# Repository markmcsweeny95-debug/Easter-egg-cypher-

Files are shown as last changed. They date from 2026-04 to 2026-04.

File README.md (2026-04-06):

# Easter-egg-cypher-
I am hosting an easter egg hunt for some family friends this year and i want to make it super exciting so i will use an arduino and a joystick where they will find clues (icons) and when they put them in it will give them a word and that will be their next clue.










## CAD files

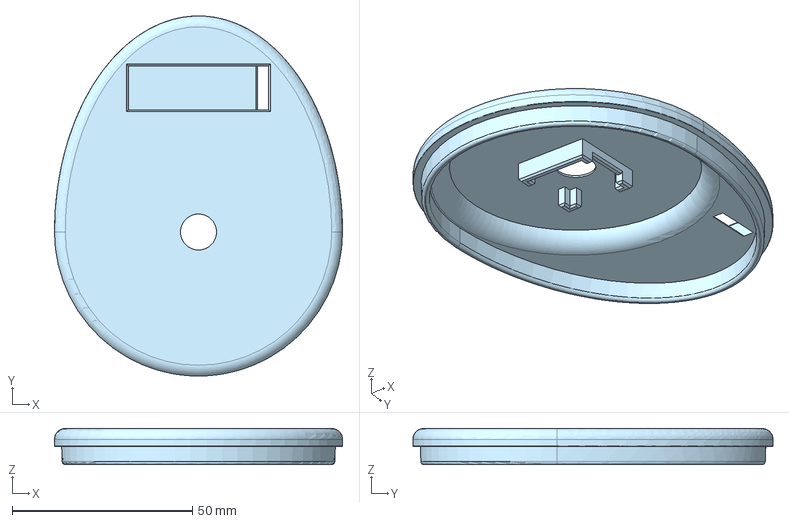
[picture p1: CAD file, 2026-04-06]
Easter egg cypher LID.step
80.0 x 100.0 x 10.0 mm

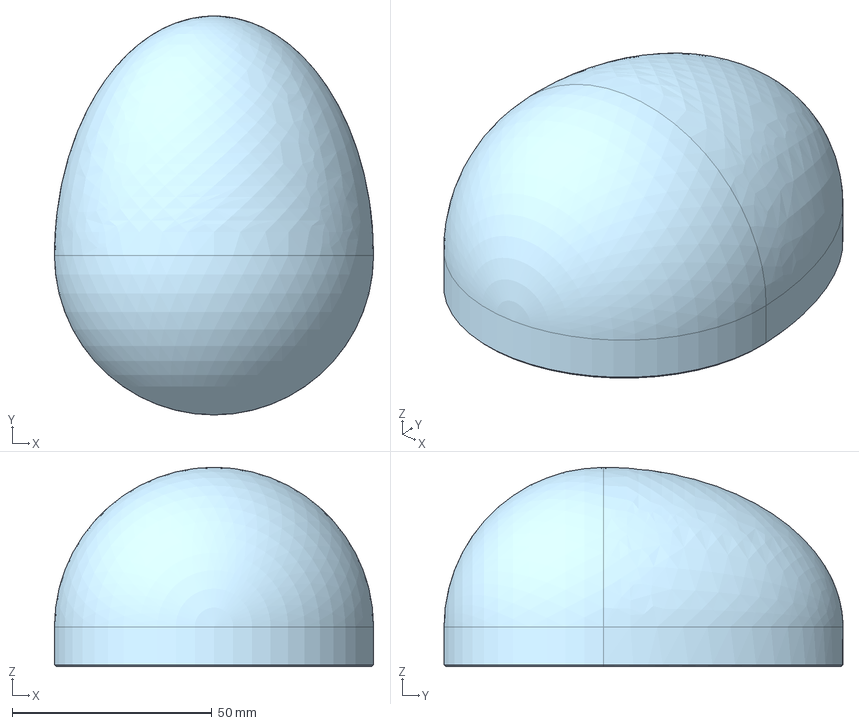
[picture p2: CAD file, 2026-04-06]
Easter egg cypher body.step
80.0 x 100.0 x 50.0 mm

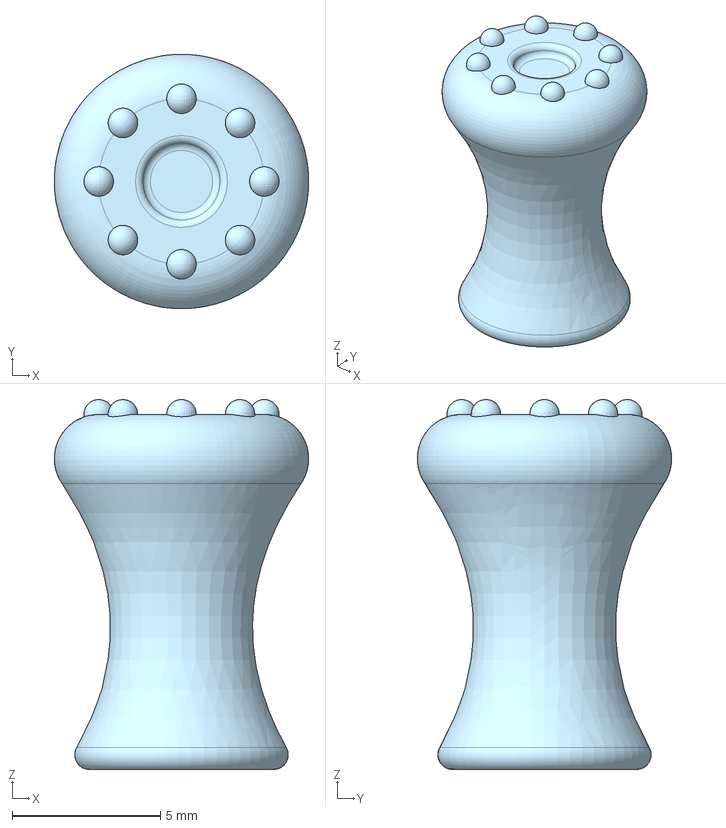
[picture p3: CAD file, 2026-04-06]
Joystick model.step
8.59 x 8.59 x 12.5 mm

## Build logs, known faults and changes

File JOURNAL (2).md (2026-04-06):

<!--
  This journal is auto generated by Stasis.
-->

# 4/6/2026 1 PM - Wiring parts

_Time spent: 0.4h_

Wiring the joystick module, OLED display, ESP32 S3 and Buzzer together.

-     Joystick wiring 
- -Ground to ESP32 ground
- -+5V to ESP32 3.3V 
- -VRx to GPIO 1 
- -VRy to GPIO 2 
- -SW to GPIO 4 
-      OLED display wiring
- -SCK to GPIO 9
- -SDA to GPIO 8
- -VCC to 3.3v 
- -Ground to ESP32 ground
- 
-       AI DECLARATION (READ!)
- Used some very bad ai code to test that all the wiring was correct by testing the buzzer, OLED and joystick. I did this so i could quickly test the wiring before i move onto prooperly coding it
- 
-     Wiring images 
- 










# 4/6/2026 10 AM - Created final lid design and final body design

_Time spent: 0.9166666666666666h_

Finalised my 3d models...

- I now have completely finished 3d models of mmy design which i have also 3d printed which means that the next stage is wiring the parts together, posssibly soldering and then also writing the code for the project as well as painting the plastic egg to look more easter-y 
-     The finished 3d models (images)
- 










-     The Final lid model
-     Key features
- -Thinned out circular section on back to save space and filament 
- -Friction joystick mount 
- -Friction mounted OLED screen with pin holes through back to allow easy wiring 
- -Drafted lip which allows it to connect to main body tightly 
- -Circular hole in front for joystick arm to poke through 
- The thinned out section of the lid is really important because it allows the joystick body to be pushed right up to it meaning that there is plenty of clearence for the joystick arm on the other side. The thinned out section is 0.5mm thick which means there it needs the support from the surrounding thicker areas otherwise it would flex. The circular thinner section also looks really cool when you shine a torch from the other side because th elight goes through it, i may add an led strip in possibly as a feature to really enhance this feature. 
- The friction joystick mount was tricky to design because it involved taking very precise measuremts of the joystick module so that it holds it tightly so it doesn't fall out but i also had to be careful not to make the walls of it too high because then it would intefere with some of the moving parts of the joystick body which could damage the component or cause some really weird results. I had to use a friction mount because the plastic wall was no longer thick enough to support using a screw to hold in the joystick. It has some small chamfers at the top which allow the joystick to enter smoothly. 
- The friction mounted OLED screen design has not changed at all since the last design 
- The drafted lip has not changed since the last design 
- The circular hole in the front of the lid was designed to allow the joystick arm and the joystick attatchment to easily fit through it while also not being in the way of allowing the joystick arm to freely move. I designed it to be 10mm but the joystick hole is only 8mm, this means there is a clearance near the moving parts and also exposes some of the shiny metal which gives it a quite luxurious look.
-      The final model body
-      Key features 
- -Thick edge lip to attatch onto lid 
- -Flat section for 10mm to add extra space 
- -Smooth surface design 
- Most of the body is just 1mm thick which allows me to save filament in the areas that don't need strength however, at the edge of the body where the body meets the drafted edge of the lid i created it 2mm thick so that it has extra strength which means it is less likely to break when disconnecting the parts. 
- At the edge where the body meets the lid i created a section which goes vertically up for 10mm which creates extra space in the egg shape without maing it seem like it hs lost too much of the egg shape. 
-      Photos of the 3d printed models 



























# 4/5/2026 4 PM - Created 2 custom joysticks

_Time spent: 0.75h_

-      Summary
- Designed some joysticks which are much thinner than my current one so won't have limited movement because of the surface of the egg. 
-     The 1st model
- The 1st model i created was very basic and took me 7 mins to model on onshape, this model was a simple pin shape where it had a large enough hole in the bottom to slot onto they joystick component but then had very little extra material anywhere else, this design was inspired by a RC planes joystick which is long and thin to allow precise control. The model worked well although i think that the sharp point of it would be too sharp for the young children to use and the hole in the bottom was too large and caused it to come off occassionaly. 
-     Images of 1st joystick idea 
- 










-     The 2nd model
- The 2nd model took me a lot longer to design (34 mins ) in onshape as it was more detailed and one of the tools i was trying to use wan't working for some reason so i designed it slightly differently.  I did try to record a lapse for it but only noticed it wasn't recording after 5 mins so ahhhhhhh :(((  . The second model was designed to have a lot more grid on the thumb/ finger while also having a less sharp point which would harm children. I also designed it to be shorter so it protruded out of the main body less. I used small lumps on the top surface to add the grip to the joystick as well as using a design which is thinner in the middle giving the eppearance of having a much wider top which makes it look closer to the original without interfering with the body of the egg 
- 
-     Images of 2nd model
- 










-     Conclusion
- I will sue the 2nd model of the joystick for my design because of the increased grip and the lack of sharp corners, i may adjust it though so it sits further down the shaft of the joystick in future












# 4/5/2026 9 AM - Created an almost finished 3d model of the lid

_Time spent: 1.183333333333333h_

Creating a detailed model of the lid for my easter egg cypher case...

-     Screenshots of CAD models 





-     Summary
- 
- I have created the almost final iteration of the easter egg cypher lid casing, the casing shape is inspired by the classic easter egg as well as being a shape which is easy to hold in a childs hand. 
-     Key features
- The final model has a few key features which make it so good including:
-  -Screw mounted joystick
- -Push fit OLED display hole
- -Rounded top surface 
- -Drafted lip for connecting parts together 
- 
- The features i talked about can be seen in the pictures of the 3d printed model below. 
- -The screw mounted joystick was designed this way so that it didn't require any glue to hold in but also would have anough strength to withstand it being pushed down and moved from left to right in quick succession. I designed the screw holes as a long bar which meant if i hadn't designed them perfectly the screws would still screw into the joystick board correctly. The main problem i have with the joystick is that because the lid is so thick this means that the way it has been mounted it leaves the joystick with very limited movement so i may design a custom joystick bit to fit onto the metal shaft which does not hit the model as much because it will be thinner. I was also thinking about desoldering the wire bits from the joystick in order to mount them on the other side so there would be more space or i could model a cut out in the lid so it is thinner where the joystick is so it has less inteference. 
- -The OLED screen cutout was very simple to design because i took very detailed measurents of the OLED screen size and then i used these to model a cut out into the lid so that the screen sits flush with the surface. However, i later adjusted it so it is about 0.5mm below flush so that if it gets dropped the screen will be protected and not smash easily. The press fit when 3d printed fits well and when i tested it by shaking it around it doesn not fall out, this minimises the need for using any glue which could damage the component. The gap all the way through the lid for the OLED is for the wires to go through so that they are not visible from the front. 
- -The rounded top surface was made simply using a 3mm fillet which was the perfect radius so it feels smooth but also doesn't intefere with the edges of the OLED screen. The rounded surface should also make it less likely to cause the children harm than a sharp edge and adds to the easter aesthetic a bit more. 
- -The drafted lip was designed so that the lid can have a push fit connection with the base of the model meaning no glue has to be used and it can be taken back off for repairing inside elctronics. The draft was made at a 3 degrees so that it slides in an dout smoothly while still having enough grip to not fall off, might adjust this to 2 or 1 degrees if it falls off to easily
- 
-     3d printed the models to test fit parts

















# 4/4/2026 6 PM - CAD modelling on lapse

_Time spent: 0.4333333333333333h_

Creating a rough 3D Model of my idea...





-     Screenshots of my CAD model in onshape

The 3d models i have created are not finished 3d models but a rough demonstration of how my product could look like, the product on the left is a rough model of my esp32 which i used when creating the size of the product to ensure there would be space to fit it. The rough model i created was designed with the half egg shape to suit the easter theme as well as heving the smooth edges which will allow it to fit comfortably into the childs hand without major discomfort. The hollow half egg shape also provides a large amount of space inside to store the battery and the esp32. I also 3d printed the top face of the model which featured the mounting holes for the joystick and the OLED display. When i tested it the OLED display fit well although, the joystick hole was not deep enough and had nowhere for the cables to go to without creating a visual mess. For my next model i will design it so that the board of the joystick can sit in the half egg shell and only the moving bit will poke through the model. I will attatch the joystick onto the 3d printed model using screws so i should consider designing some appropriately sized holes in the model for the screws to screw into or dill them out later. 





-     The parts i 3d printed






# 4/4/2026 3 PM - Brainstorming Ideas

_Time spent: 2.166666666666667h_

Brainstorming (live in the devlog)...
-     Context 
- Every year around easter time i host an easter egg hunt for a family friends children who are 4 and 9 this year. The easter egg hunt i plan to set out will be where they get a riddle clue which will lead them to the next egg to find. Each of the eggs will have a clue on it but this year i plan to put on a selection of easter related symbols instead and the job of the decypher is so they can input the selection of symbols they find on the back of each paper egg into it using the joystick by flicking it in 1 of 4 directions for each symbol. Once they do this the product will output to the children the next clue of what they are looking to find and this will continue until they find the last paper egg which will have a clue to the final chocolate egg location. 

-     What is it? 
- The product is going to be a  portable handheld device which will be programmed in such a way that every input of the joystick is unique. The joystick will have 4 positions in which it can be positioned and each of these will correlate to an easter icon (egg, 
chick, bunny, flower). 

-     How does it work?
- When one postition is selected it will wait a set period of time to check if the user will input a second position and it will then wait again (this process repeats until the user doesn't touch the joystick for a few secs and the code assumes they have finished entering the position of sequences) once it has confirmed they have finished their sequence the code will search for this sequence in the datebase and output the word that was stored in the database for that sequence onto the small OLED screen built in. The clue will stay on screen until the next joystick position is sensed (until they find the next clue and start decoding it)

-     Who is it for?
- My project is designed to be used by small children which are family friends and will be designed for children between the age of 3 and 9. Because of the youngest child being 3, almost 4 i should design my product so that it can either fit into their hands or it should be held by the older child and placed on the ground to use. I should also consider the simplicity of the product to use since it may be confusing to understand for the 4 year old. My plan to combat this is by eliminating the need for words for most of it (apart from outputting them on the screen) in this case the older child will have to read out the words, although the younger child will be able to find the clues and enter them into the decypher still with no limitations. The younger child will also get to help in solving the riddles that will be shown on the screen. 

-     The design 
The physical design of the product will be 3d printed and possibly painted to look more eastery looking. The design will be 3d modelled in onshape. The design will need to be big enough to fit all the parts and as well as have holes in the right places for it to be ergenomic- ish to use. 

-     Parts list initial 
-  -Arduino Uno R3 or Esp32-S3 devkit Lipo 
- -Small OLED screen 25mm x 10mm display size 
- -Arduino Joystick
- -3D printed case 
- -AA battery/ Powerbank/ Lipo battery
- 
-     Coding 
- The project will be coded in Arduino C++ and i will learn the code for it using online resources such as w3 schools as well as coding cheat sheets and youtube tutorials. 
- 
-     Initial drawings 
- 
